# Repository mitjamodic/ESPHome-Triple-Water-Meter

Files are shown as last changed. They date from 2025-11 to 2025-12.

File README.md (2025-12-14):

# 💧 ESPHome Triple Water Meter (ESP32-S3-POE-ETH)

🌐 Languages: [🇬🇧 English](README.md) | [🇸🇮 Slovenščina](README.sl.md)

## 📘 Overview
This project provides a complete **ESPHome configuration** for monitoring **three separate water meters** using an **ESP32-S3-POE-ETH** board with integrated **Power-over-Ethernet (PoE)** and **Ethernet (W5500)** support.

It is fully compatible with **Home Assistant**, but can also be monitored directly via the built-in **web server** using the device’s IP address.

<p>
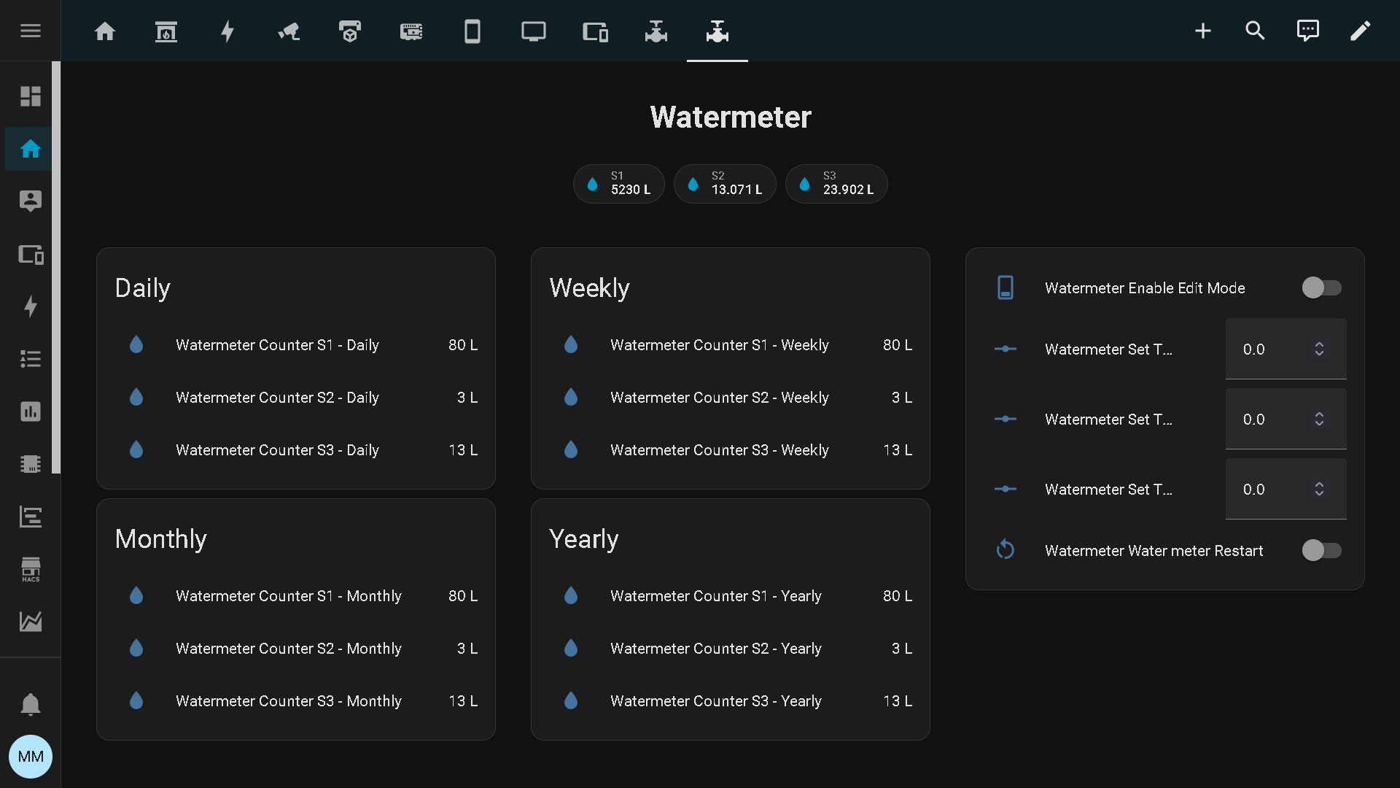
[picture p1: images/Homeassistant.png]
  
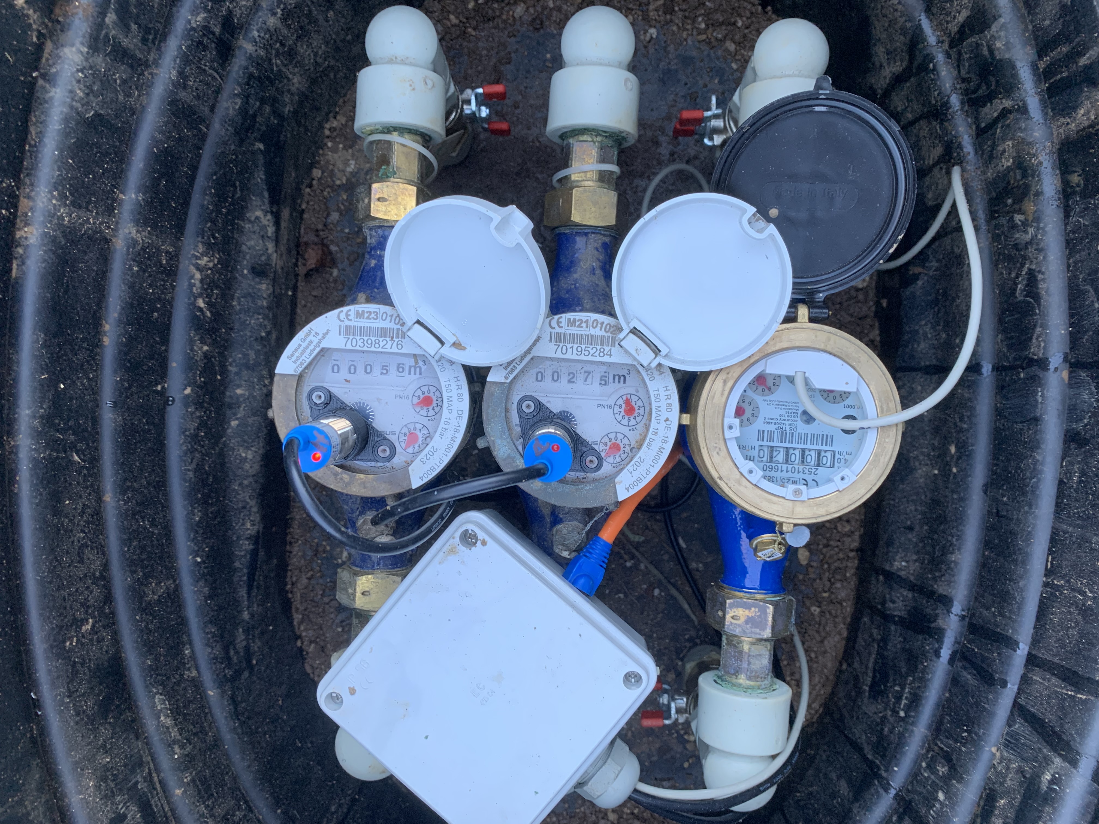
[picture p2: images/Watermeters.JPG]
  
</p>

---

## ⚡ Key Features
- Supports **three independent water meters**
- Designed for **PoE-powered ESP32-S3-POE-ETH** (no Wi-Fi needed)
- Works with **reed switches** or **NPN NO inductive sensors**
- Tracks **daily, weekly, monthly, and yearly** consumption
- Built-in **auto reset** at midnight, Monday, first of month/year
- Manual input for initial counter values
- Includes **web_server** for standalone monitoring
- **Restart switch** available via Home Assistant
- Stable and reliable — tested for several months in real use

---

## 🧠 Hardware Setup

### 🪛 Controller
- **ESP32-S3-POE-ETH** (with W5500 Ethernet + PoE module)  
  🔗 https://www.aliexpress.com/item/1005007945002026.html

---
### 🌐 Advantages of Using PoE

Using Power-over-Ethernet (PoE) provides a highly reliable and practical way to power the ESP32-S3-POE-ETH module:

✔ Stable power delivery over long distances — PoE works up to 100 meters without noticeable voltage drop or interference

✔ Single-cable installation — both power and data through the same Ethernet cable

✔ Improved reliability compared to Wi-Fi setups, especially for utility monitoring

✔ No need for local power adapters, outlets, or USB cables near the installation point

If you don’t have a PoE switch, you can still use PoE by adding a PoE injector, which provides power to the Ethernet cable while keeping the network connection simple and robust.

---

### 🔌 Wiring Schematics

Below is the complete wiring diagram used in this project:

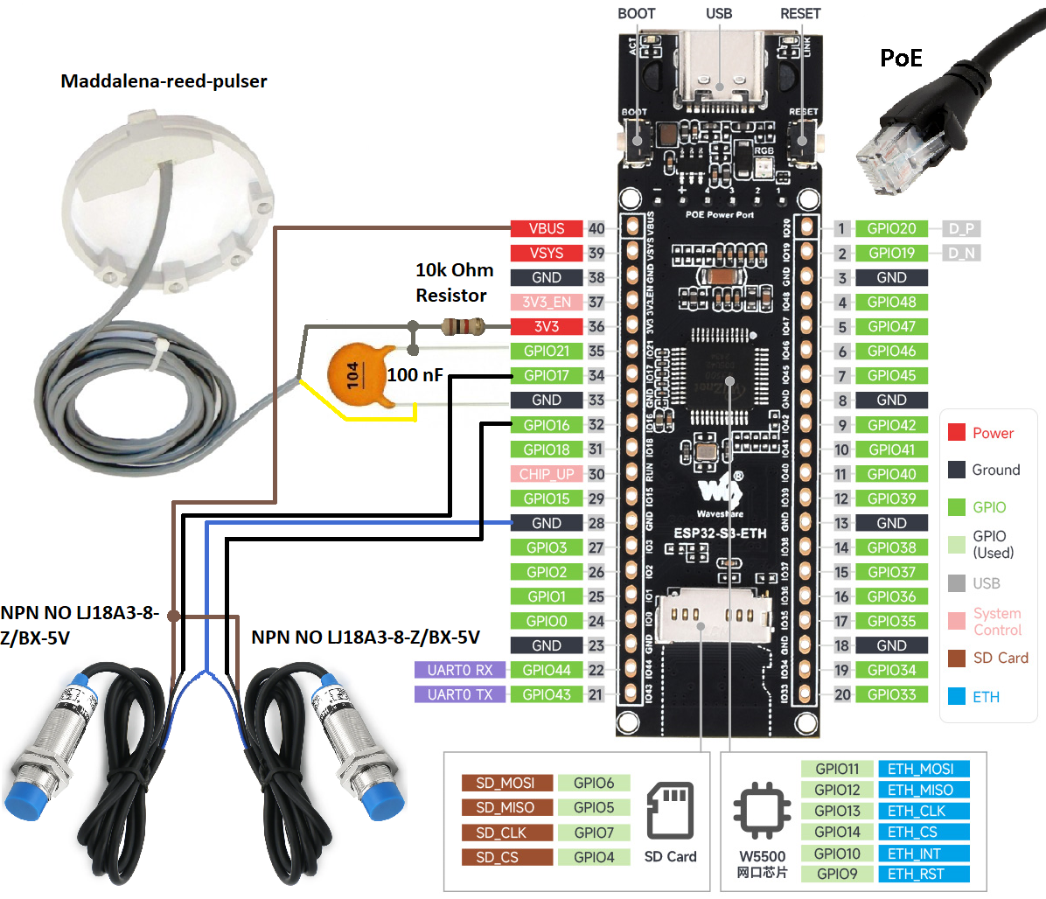
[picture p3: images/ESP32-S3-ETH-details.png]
ESP32-S3 Wiring Diagram


*Detailed view of the ESP32-S3 connections, sensors, power routing, and Ethernet interface.*

---

## 💧 Water Meters and Sensors

### **S1 – Maddalena DS TRP**
- Uses **REED SWITCH TRP PULSER**

> **Note for users in Slovenia:**  
> Since I am based in Slovenia, I obtained the Maddalena RSTP pulse emitter through the official SENSUS distributor **ARSS d.o.o.**  
>  
> The company specializes in water-metering solutions and digitalization technologies. Their team was extremely friendly, responsive, and helpful — I had the pulse emitter delivered the very next day.  
>  
> If you are facing a new challenge related to water-consumption monitoring, they may already have a suitable solution. They also offer a wide range of sensors and accessories for different types of water meters.  
>  
> 🔗 Website: https://arss.si/  
> 📧 Contact: info@arss.si

<p align="left">
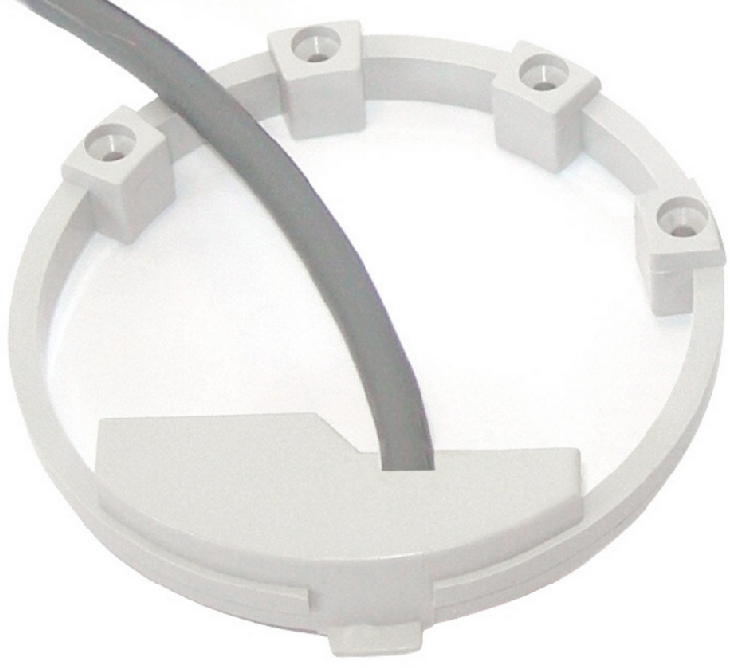
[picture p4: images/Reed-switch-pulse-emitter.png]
  
</p>

- Includes hardware **debounce circuit**:
  - 100 nF ceramic capacitor (104)
  - 10 kΩ pull-up resistor

---

### **S2 and S3 – Sensus 420**
- Use **inductive NPN NO sensors (LJ18A3-8-Z/BX-5V)**  
  🔗 https://www.aliexpress.com/item/1005004867517992.html
- Powered at **5 V**
- Connected directly with internal pull-ups enabled in software:

```yaml
mode: INPUT_PULLUP
```

*Tested for several months — **no false triggers or interference**.*

---

## ⚙️ Software Details

### 🔌 Communication
- Ethernet (W5500)
- PoE power supply
- No Wi-Fi configuration required

---

### 📊 Data Points per Meter

Each meter (`S1`, `S2`, `S3`) provides the following sensors:

| Entity | Description |
| --- | --- |
| **Total** | Lifetime total water usage (liters)  |
| **Daily** | Reset every midnight |
| **Weekly** | Reset every Monday |
| **Monthly** | Reset on the 1st of each month |
| **Yearly** | Reset on January 1st |
| **Current consumption** | Tracks short-term water events |
| **Last consumption** | Holds most recent event before reset |

---

### 🔁 Automatic Resets

| Period  | Trigger Time | Action |
| --- | --- | --- |
| Daily | Every midnight | Reset daily counters |
| Weekly  | Monday at midnight | Reset weekly counters  |
| Monthly | 1st day of month | Reset monthly counters |
| Yearly  | January 1st | Reset yearly counters  |

---

## 🧮 Manual Initialization

If you need to set your water meter totals manually (for example when first installing the system), the firmware now includes a simple Edit Mode that enables manual input directly from Home Assistant or the web interface.

🟦 How It Works

Enable Edit Mode
Toggle the switch “Enable Edit Mode” to ON.
This unlocks the manual input fields.

Enter Initial Values
Adjust the values for:

Set Total S1

Set Total S2

Set Total S3

Enter the total water usage in liters as shown on your physical meters.

Apply the New Values
After entering the totals, toggle the “Restart” switch.
The device will reboot and load the new values as the starting point for all counters.

📝 Notes

Edit Mode automatically locks again after a reboot to prevent accidental changes.

If you need to correct values later, simply repeat the steps above.

---

## 🌐 Web Interface

The configuration includes a built-in **web server**.  
Once connected to the network, open your browser and visit:

```
http://<device_ip>
```

You’ll see live readings from all three water meters.

---

## 🔄 Restart Button

A **software restart button** is available through Home Assistant:

```yaml
button:
  - platform: restart
    name: "${friendly_name} Restart"
```
---

## 🛠 Installation Options

There are two ways to install the firmware onto your ESP32-S3-POE-ETH controller:

### 1️⃣ Install using the ESPHome Builder (recommended for Home Assistant users)
If you use Home Assistant and have ESPHome integrated, simply upload the provided YAML configuration into ESPHome and compile/flash the firmware directly from the ESPHome dashboard.

### 2️⃣ Install using the precompiled .BIN file (for users without Home Assistant)
For users who do **not** use Home Assistant, a ready-to-flash **`.bin` firmware file** is provided.

You can upload it directly to your controller using the official ESPHome web installer:

https://web.esphome.io/

Connect the ESP32-S3-POE-ETH via USB, open the page, click **Install**, choose the provided `.bin` file — and the device will be flashed.

After installation, you can monitor all three water meters through the built‑in **web interface**, without requiring Home Assistant.

---

## MQTT Support (optional)

The project supports MQTT for integration with other systems (Node-RED, Grafana, ioBroker …).

MQTT is not required for use with Home Assistant (ESPHome API).

👉 Detailed instructions can be found in:
[MQTT_README_EN.md](MQTT/MQTT_README_EN.md)

---

## 🧰 Dependencies
* **ESPHome** ≥ 2024.6.0  
* **Home Assistant** (optional, but recommended)  
* Ethernet support enabled in your ESPHome installation  

---

## ⚖️ License
MIT License

---

## 🚀 Future Improvements 
* Flow rate calculation support  
* Adaptation for different ESP32 boards  
* Optional OLED display for local readings  

---

## 🙌 Credits
Developed and tested by **Mitja Modic**  
Inspired by real-world use for reliable water metering over Ethernet (PoE) connections.

---

⭐ *If you find this project useful, please give it a star on GitHub!* ⭐

### ☕ If you find this project useful and would like to support my work, you can buy me a coffee:



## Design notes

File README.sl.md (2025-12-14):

# 💧 ESPHome Trojni Merilnik Vode (ESP32-S3-POE-ETH)

🌐 Jeziki: [🇬🇧 English](README.md) | [🇸🇮 Slovenščina](README.sl.md)

## 📘 Pregled
Ta projekt vsebuje popolno **ESPHome konfiguracijo** za spremljanje **treh ločenih vodomerov** z uporabo **ESP32-S3-POE-ETH** ploščice z integriranim **Power-over-Ethernet (PoE)** in **Ethernet (W5500)** modulom. 

Popolnoma je združljiv s **Home Assistant** sistemom, lahko pa ga spremljaš tudi neposredno prek vgrajenega **spletnega strežnika** z uporabo IP-naslova naprave.

<p>
  
  
</p>

---

## ⚡ Glavne značilnosti
- Podpira **tri neodvisne vodomere**
- Namenjeno za **PoE napajano ESP32-S3-POE-ETH** ploščo (brez Wi-Fi)
- Deluje z **reed stikali** ali **NPN NO induktivnimi senzorji**
- Spremlja **dnevno, tedensko, mesečno in letno** porabo
- Vgrajeni **samodejni reseti** opolnoči, ob ponedeljkih, prvi dan v mesecu in prvi dan v letu
- Ročni vnos začetnih vrednosti števcev
- Vključen **web_server** za samostojno spremljanje
- **Restart stikalo** dostopno prek Home Assistanta
- Stabilno in zanesljivo — preizkušeno več mesecev v realnem okolju

---

## 🧠 Strojna oprema

### 🪛 Krmilnik
- **ESP32-S3-POE-ETH** (z W5500 Ethernet + PoE modulom)  
  🔗 https://www.aliexpress.com/item/1005007945002026.html

---

### 🌐 Prednosti uporabe PoE

Uporaba Power-over-Ethernet (PoE) je zelo zanesljiv in praktičen način napajanja ESP32-S3-POE-ETH modulov:

✔ Stabilno napajanje na dolge razdalje — PoE deluje do 100 m brez opaznih izgub ali motenj

✔ En kabel za vse — napajanje in podatki prek istega Ethernet kabla

✔ Večja zanesljivost v primerjavi z Wi-Fi, kar je idealno za merjenje porabe

✔ Ni potrebe po lokalnih napajalnikih, vtičnicah ali USB kablih na mestu montaže

Če nimaš PoE stikala, lahko PoE vseeno uporabljaš s PoE injektorjem, ki v Ethernet kabel doda napajanje in ohranja enostavno ter robustno povezavo.

---

### 🔌 Shema ožičenja

Spodaj je celotna shema ožičenja, uporabljena v tem projektu:

ESP32-S3 Wiring Diagram

*Pogled podrobnosti ESP32-S3 povezav, senzorjev, napajanja in Ethernet vmesnika.*

---

## 💧 Vodomeri in senzorji

### **S1 – Maddalena DS TRP**
- Uporablja **REED SWITCH TRP PULSER**

> **Opomba za uporabnike v Sloveniji:**  
> Ker sem iz Slovenije, sem Maddalena RSTP stikalo pridobil preko slovenskega distributerja za SENSUS – podjetja **ARSS d.o.o.**  
>  
> Podjetje se ukvarja z iskanjem rešitev na področju merjenja in digitalizacije porabe vode.  
> Osebje je bilo zelo prijazno, hitro in odzivno – stikalo sem prejel praktično že naslednji dan.  
>  
> Če se soočate z izzivi pri spremljanju porabe vode, jih lahko kontaktirate – morda so podobno težavo že rešili.   
> Na voljo imajo tudi široko ponudbo senzorjev za različne tipe vodomerov.  
>  
> 🔗 Spletna stran: https://arss.si/  
> 📧 Kontakt: info@arss.si

<p align="left">
  
</p>

- Vključuje strojni **debounce**:
  - 100 nF keramični kondenzator (104)
  - 10 kΩ pull-up upor

---

### **S2 in S3 – Sensus 420**
- Uporabljata **induktivna NPN NO senzorja (LJ18A3-8-Z/BX-5V)**  
  🔗 https://www.aliexpress.com/item/1005004867517992.html
- Napajana pri **5 V**
- Povezana neposredno z internimi pull-up upori, omogočenimi v programski opremi:

```yaml
mode: INPUT_PULLUP
```

*Testirano več mesecev — **brez lažnih impulzov ali motenj**.*

---

## ⚙️ Podrobnosti programske opreme

### 🔌 Komunikacija
- Ethernet (W5500)
- PoE napajanje
- Ni potrebe po Wi-Fi nastavitvah

---

### 📊 Podatkovne točke za vsak vodomer

Vsak vodomer (`S1`, `S2`, `S3`) zagotavlja naslednje senzorje:

| Entiteta | Opis |
| --- | --- |
| **Skupaj** | Življenjska skupna poraba (litri) |
| **Dnevno** | Reset vsak dan opolnoči |
| **Tedensko** | Reset vsak ponedeljek opolnoči |
| **Mesečno** | Reset prvi dan vsakega meseca |
| **Letno** | Reset 1. januarja |
| **Trenutna poraba** | Sledi kratkoročnim vodnim dogodkom |
| **Zadnja poraba** | Zadnji dogodek pred resetom |

---

## 🔁 Samodejni reseti

| Perioda | Čas sprožitve | Dejanja |
| --- | --- | --- |
| Dnevno  | Vsak dan opolnoči | Reset dnevnih števcev |
| Tedensko| Ponedeljek opolnoči | Reset tedenskih števcev  |
| Mesečno | 1. v mesecu opolnoči  | Reset mesečnih števcev |
| Letno | 1. januarja | Reset letnih števcev |

---

## 🧮 Ročna inicializacija

Če moraš ob prvi namestitvi ali ob menjavi naprave vnesti trenutne vrednosti vodomerov, lahko zdaj to narediš enostavno preko Načina za urejanje (Edit Mode), brez spreminjanja YAML kode.

🟦 Kako deluje

Vklopi Edit Mode
Preklopi stikalo »Enable Edit Mode« na ON.
S tem omogočiš ročni vnos vrednosti.

Vnesi začetne vrednosti
Nato vneseš vrednosti za:

Set Total S1

Set Total S2

Set Total S3

Vpiši skupno porabo v litrih, ki jo trenutno kažejo tvoji dejanski vodomeri.

Potrdi nove vrednosti
Ko so vse vrednosti vnesene, preklopi stikalo »Restart«.
Modul se bo ponovno zagnal in naložil nove začetne vrednosti kot osnovo za vse števce.

📝 Opombe

Po ponovnem zagonu se Edit Mode samodejno izklopi, da prepreči nenamerne spremembe.

Če želiš vrednosti kasneje ponovno popraviti, postopek samo ponoviš.

---

## 🌐 Spletni vmesnik

Konfiguracija vključuje vgrajeni **spletni strežnik**.  
Ko je naprava povezana v omrežje, v brskalnik vpiši:

```
http://<ip_naprave>
```

Prikazale se bodo trenutne meritve za vse tri vodomere.

---

## 🔄 Restart tipka

**Programski restart** je na voljo prek Home Assistanta:

```yaml
button:
  - platform: restart
    name: "${friendly_name} Restart"
```
---

## 🛠 Možnosti namestitve

Na voljo sta dva načina namestitve programske opreme na ESP32-S3-POE-ETH krmilnik:

### 1️⃣ Namestitev z uporabo ESPHome Builderja (priporočeno za uporabnike Home Assistanta)
Če uporabljaš Home Assistant in imaš nameščen ESPHome, preprosto naložiš priloženo YAML konfiguracijo v ESPHome in preko ESPHome vmesnika skompiliraš ter naložiš firmware na krmilnik.

### 2️⃣ Namestitev s predpripravljeno .BIN datoteko (za uporabnike brez Home Assistanta)
Za uporabnike, ki **ne** uporabljajo Home Assistanta, je na voljo že pripravljena **`.bin` datoteka.** .

Na napravo lahko naložiš neposredno prek uradnega ESPHome spletnega orodja:

https://web.esphome.io/

Preprosto priključi ESP32-S3-POE-ETH preko USB-ja, odpri spletno stran, klikni **Install**, izberi priloženo `.bin` datoteko – in namestitev je končana.

Po namestitvi lahko porabo vseh treh vodomerov spremljaš prek vgrajenega **spletnega vmesnika**, , brez Home Assistanta.

---

## MQTT podpora (neobvezno)

Projekt podpira MQTT za integracijo z drugimi sistemi (Node-RED, Grafana, ioBroker …).

MQTT ni potreben za uporabo z Home Assistantom (ESPHome API).

👉 Podrobna navodila so v:
[MQTT_README_SI.md](MQTT/MQTT_README_SI.md)

---

## 🧰 Odvisnosti
* **ESPHome** ≥ 2024.6.0  
* **Home Assistant** (neobvezen, vendar priporočljiv)  
* Podpora za Ethernet mora biti omogočena v tvoji ESPHome namestitvi  

---

## ⚖️ Licenca
MIT License

---

## 🚀 Prihodnje izboljšave
* Izračun pretoka v realnem času  
* Prilagoditev za različne ESP32 plošče  
* Opcijski OLED zaslon za lokalni prikaz  

---

## 🙌 Zahvale
Razvijal in testiral **Mitja Modic**  
Navdihnjen z realnimi potrebami za zanesljivo merjenje porabe vode preko Ethernet (PoE) povezav.

---

⭐ *Če ti je projekt koristen, mi na GitHubu podari zvezdico!* ⭐

---

### ☕ Če vam je projekt koristen in bi radi podprli moje delo, me lahko povabite na kavo



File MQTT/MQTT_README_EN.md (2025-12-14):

### What is MQTT and why use it

MQTT support allows the watermeter device to act as a **generic data
source**, independent of Home Assistant.

MQTT is recommended if you: - use **Node-RED** - store data in
**InfluxDB / Grafana** - integrate with other platforms - require device
availability monitoring

⚠️ **MQTT is optional**.

MQTT is implemented as a separate ESPHome package.

To enable MQTT support:
- download `mqtt.yaml`
- place `mqtt.yaml` in `MQTT` folder in same directory as the main ESPHome YAML file
- include it using `packages`

------------------------------------------------------------------------

### Basic configuration

The MQTT configuration is defined in the `mqtt.yaml` file, while sensitive data is stored in `secrets.yaml`.

#### `secrets.yaml`

``` yaml
mqtt_broker: 192.168.1.10
mqtt_user: mqtt_user
mqtt_pass: mqtt_password
```

#### ESPHome configuration

``` yaml
packages:
  mqtt: !include MQTT/mqtt.yaml
```

#### `MQTT.yaml`

``` yaml
mqtt:
  broker: !secret mqtt_broker
  username: !secret mqtt_user
  password: !secret mqtt_pass
  topic_prefix: watermeter
  discovery: false
```

------------------------------------------------------------------------

### MQTT topics

    watermeter/

Examples:

    watermeter/sensor/counter_s1_total/state
    watermeter/status

------------------------------------------------------------------------

### Home Assistant notice

Disable discovery to prevent duplicate entities:

``` yaml
discovery: false
```

Remove the MQTT device manually if already discovered.

------------------------------------------------------------------------

### Disabling MQTT

Remove the `mqtt:` block if not required.

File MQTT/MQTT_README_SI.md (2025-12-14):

### Kaj je MQTT in zakaj ga uporabiti

MQTT podpora omogoča, da watermeter naprava deluje kot **splošen vir
podatkov**, neodvisno od Home Assistanta.

MQTT je priporočljiv, če: - želiš podatke uporabljati v **Node-RED** -
zapisuješ podatke v **InfluxDB / Grafana** - uporabljaš drug sistem
(ioBroker, OpenHAB, lastne aplikacije) - želiš večjo zanesljivost in
lažje spremljanje statusa naprave

⚠️ **MQTT ni obvezen** za delovanje z Home Assistantom.

MQTT je implementiran kot ločen ESPHome paket.

Če želiš MQTT podporo:
- prenesi `mqtt.yaml`
- shrani `mqtt.yaml` v mapo `MQTT` kjer je glavni YAML
- vključi ga preko `packages`

------------------------------------------------------------------------

### Osnovna MQTT konfiguracija

MQTT konfiguracija je definirana v `mqtt.yaml` datoteki, občutljivi
podatki pa se hranijo v `secrets.yaml`.

#### `secrets.yaml`

``` yaml
mqtt_broker: 192.168.1.10
mqtt_user: mqtt_user
mqtt_pass: mqtt_password
```

#### ESPHome konfiguracija

``` yaml
packages:
  mqtt: !include MQTT/mqtt.yaml
```

#### `MQTT.yaml`

``` yaml
mqtt:
  broker: !secret mqtt_broker
  username: !secret mqtt_user
  password: !secret mqtt_pass
  topic_prefix: watermeter
  discovery: false
```

------------------------------------------------------------------------

### MQTT teme

Vse MQTT teme so združene pod osnovno temo:

    watermeter/

Primeri objav:

    watermeter/sensor/counter_s1_total/state
    watermeter/sensor/counter_s1_daily/state
    watermeter/sensor/counter_s2_total/state
    watermeter/status

------------------------------------------------------------------------

### Status naprave

Topic:

    watermeter/status

Payload: - `online` - `offline`

------------------------------------------------------------------------

### Home Assistant -- pomembno opozorilo

Če uporabljaš Home Assistant preko **ESPHome integracije**, priporočamo:

``` yaml
discovery: false
```

Po spremembi je potrebno **ročno odstraniti MQTT napravo** iz:

    Settings → Devices & Services → MQTT → Devices

------------------------------------------------------------------------

### Izklop MQTT

Če MQTT ne uporabljaš, odstrani ali zakomentiraj `mqtt:` blok.

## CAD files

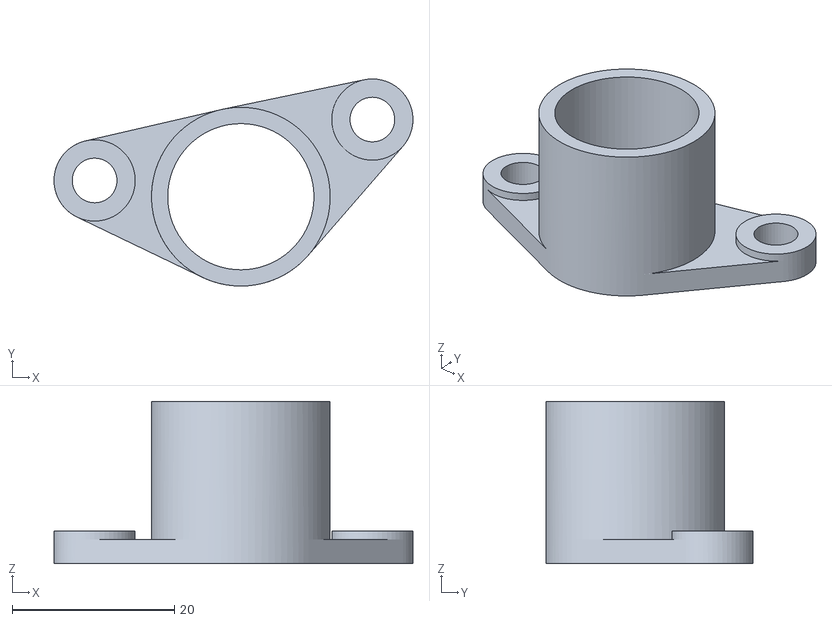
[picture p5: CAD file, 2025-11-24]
3D print STL/sensus_420_prox_hol.stl
44.2 x 25.5 x 20.0

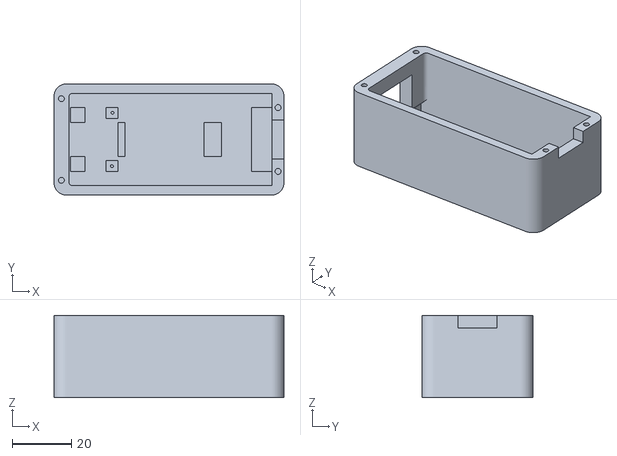
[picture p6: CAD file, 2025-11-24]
3D print STL/esp32-s3-eth_case.stl
77.5 x 37.5 x 27.8

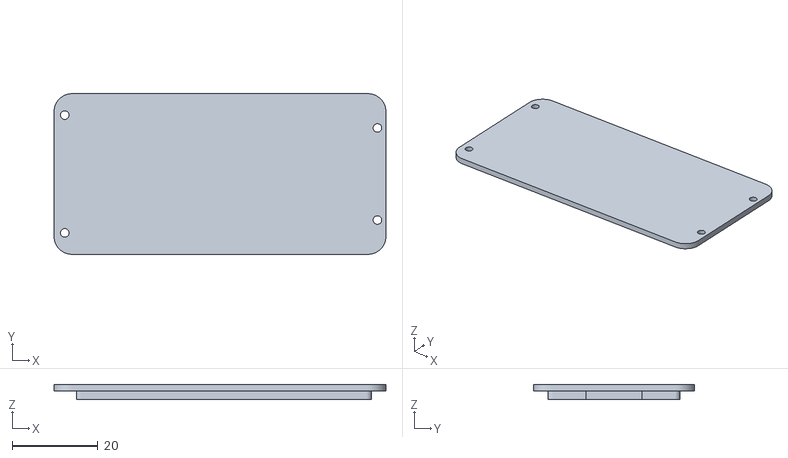
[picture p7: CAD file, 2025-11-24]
3D print STL/esp32-s3-eth_cover.stl
77.5 x 37.5 x 3.50
